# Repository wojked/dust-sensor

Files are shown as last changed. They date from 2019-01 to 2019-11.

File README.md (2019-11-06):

**This is a part of: https://dustsensor.net/**

__Links to the parts contain Banggood's affilate metadata.__

# Intro
I needed a PM2.5/PM10 sensor during this winter season. I wanted to monitor more than one room and did not want to buy multiple expensive devices.

This is an eclosure designed to fit 3 devices:
1. a PM2.5/PM10 dust sensor
2. a Wemos ESP8266-based board with an OLED display
3. a digital humidity and temperature sensor

# Parts
* Wemos NodeMCU with an OLED display
The brain of this project. Provides processing, connectivity and instant data feed on the display.
[Buy Wemos with a display](https://www.banggood.com/Wemos-Nodemcu-Wifi-For-Arduino-And-NodeMCU-ESP8266-0_96-Inch-OLED-Board-p-1154759.html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)

* Nova SDS011 
The main sensor used to measure PM2.5 and PM10
[Buy SDS011](https://www.banggood.com/Nova-PM-Sensor-SDS011-High-Precision-Laser-PM2_5-Air-Quality-Detection-Sensor-Module-p-1144246.html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)

* DHT22 (AM2302) 
Additional sensor to measure humidity and temperature
[Buy DHT22](https://www.banggood.com/AM2302-DHT22-Temperature-And-Humidity-Sensor-Module-For-Arduino-SCM-p-937403.html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)

* 4x longer M3x20 screws to hold the main case plates together 
[Buy M3x20](https://www.banggood.com/Suleve-M3CH9-50Pcs-M3-Carbon-Steel-Hex-Socket-Cap-Head-Screws-Bolts-4-20mm-Optional-Length-p-1217022.html?ID=514050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)
* 4x shorter M3x8 screws to mount the Wemos board
[Buy M3x8](https://www.banggood.com/Suleve-M3CH9-50Pcs-M3-Carbon-Steel-Hex-Socket-Cap-Head-Screws-Bolts-4-20mm-Optional-Length-p-1217022.html?ID=513285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)

# Assembly
1. Print the parts
2. Connect SDS011 to Wemos board
3. Connect DHT22 to Wemos board
4. Use 4x shorter screws to mount the Wemos board to the front plate
5. Use 4x longer screws to keep front and back plate together
6. Flash Wemos board with [ESPEasy](https://github.com/letscontrolit/ESPEasy)
7. Configure devices in ESPeasy

# Summary
When fully assembled, it should be compete with the retail products as:

* [Xiaomi PM2.5 detector](https://www.banggood.com/Original-Xiaomi-Mijia-PM2_5-Detector-Air-Quality-Tester-Monitor-OLED-Smart-Sensor-Air-Purifier-p-1330361.html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)

* [SNDWAY SW-825 Digital Air Quality Monitor](https://www.banggood.com/SNDWAY-SW-825-Digital-Air-Quality-Monitor-Laser-PM2_5-Detector-Gas-Temperature-Humidity-Monitor-p-1244753.html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)

# Please feel free to propose improvements
https://github.com/wojked/dust-sensor

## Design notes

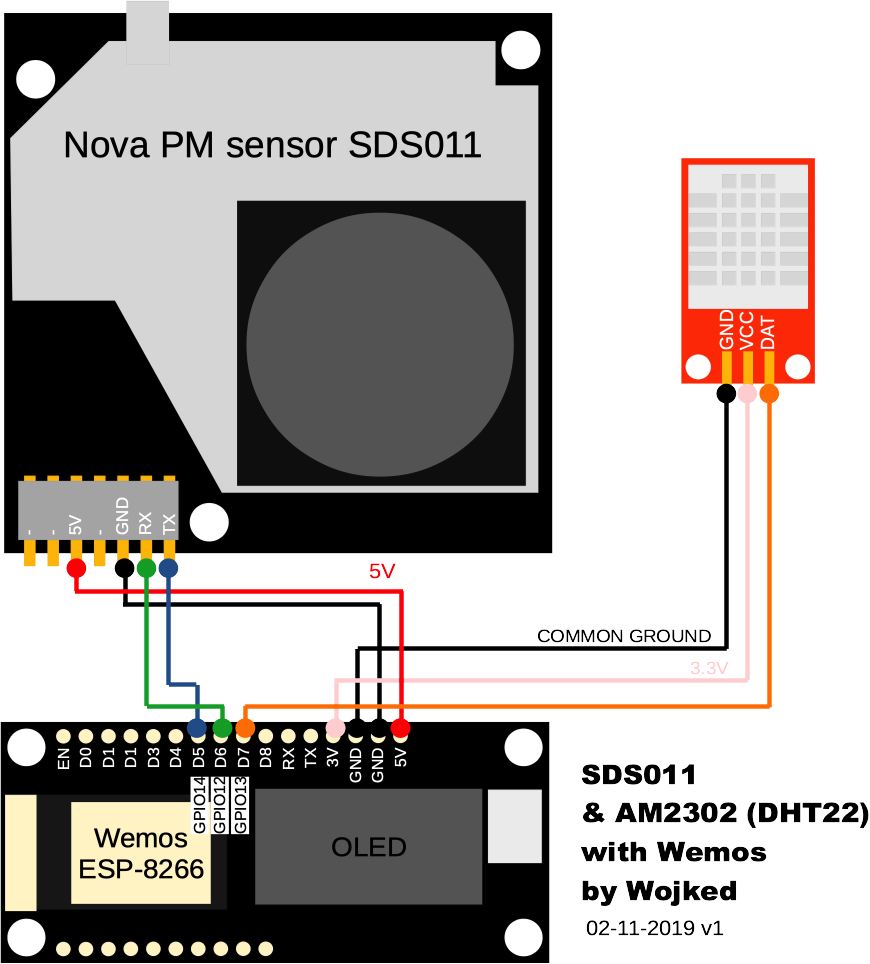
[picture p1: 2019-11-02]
diagram.png

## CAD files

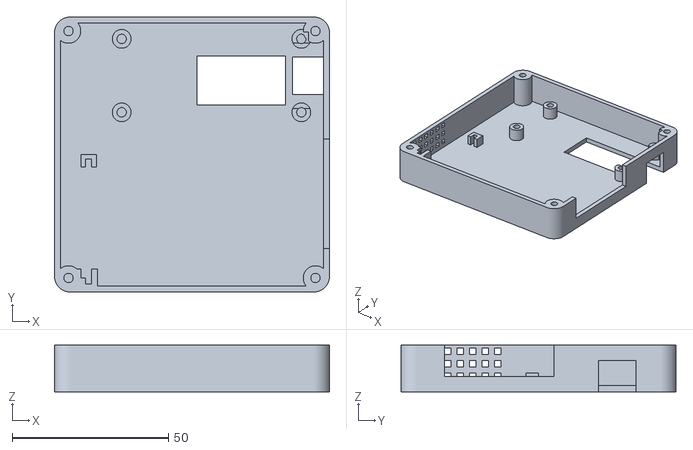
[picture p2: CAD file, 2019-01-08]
dust-sensor-front.stl
88.0 x 88.0 x 15.0

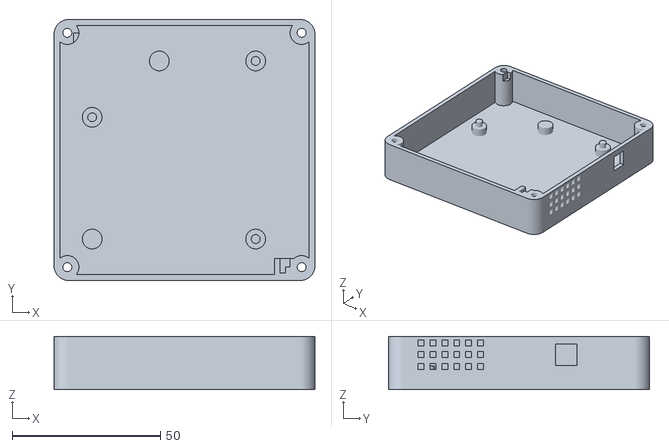
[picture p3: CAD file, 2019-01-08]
dust-sensor-back.stl
88.0 x 88.0 x 18.0

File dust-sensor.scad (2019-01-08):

EXTRA_MARGIN = 14; // initially 6
SENSOR_WIDTH = 70 + EXTRA_MARGIN;
SENSOR_HEIGHT = 70 + EXTRA_MARGIN;

BASE_THICKNESS = 2; // initially 1
CORNER_CURVE_DIAMETER = 10; // initially 3

WALL_THICKNESS = 2;
TOTAL_WALL_HEIGHT = 32; // initially 25
WALL_HEIGHT = 18;
FRONT_WALL_HEIGHT = TOTAL_WALL_HEIGHT - WALL_HEIGHT + BASE_THICKNESS - 1; // Fix with BASE_THICKNESS - 1 (initial thickness was 1)


/* [MOUNTING ELEMS] */
HOLE_DIAMETER = 3.0; // initially 2.7
HOLE_HOLDER = 6.65;
SCREW_WALL_THICKNESS = 2;
SCREW_HEAD_DIAMETER = 6.4; // M3 screw
SCREW_HEAD_THICKNESS = 3.07; // M3 screw
SCREW_OFFSET = 0.7;


//Cut-outs dimensions
CABLE_PORT_HEIGHT = 21;
AIR_INTAKE_DIAMETER = 7.15;
FAN_SIZE = 35;
FAN_HEIGHT = 10;

PCB_THICKNESS = 1.64;
TOTAL_PCB_THICKNESS = 4.10;
CHIP_THICKNESS = TOTAL_PCB_THICKNESS - PCB_THICKNESS + 1; //initially +0.5
SLOT_HEIGHT = CHIP_THICKNESS + 2.5; //initially + 2

// WEMOS
WEMOS_WIDTH = 61.5;
WEMOS_HEIGHT = 27.5;

WEMOS_TOTAL_THICKNESS = 4.8;
WEMOS_PCB_THICKNESS = PCB_THICKNESS;
WEMOS_SUPPORT_HEIGHT = WEMOS_TOTAL_THICKNESS - WEMOS_PCB_THICKNESS + 2;

WEMOS_OFFSET = 5;
WEMOS_SCREW_OFFSET = 0.5;   //initially 0.8

//DHT22
DHT_WIDTH = 21;
DHT_HEIGHT = 16;
DHT_WIDHT_WITH_HEADER = 26;
DHT_THICKNESS = 7.8;
DHT_HEADER_THICKNESS = 1.6;
DHT_BACK_OFFSET = 2;

DHT_RED_PCB_WIDTH = 40;
DHT_RED_PCB_HEIGHT = 23;
DHT_RED_PCB_THICKNESS = 1.8;
DHT_RED_PCB_OFFSET = 3;
DHT_OFFSET = 8;

OBJ_VISIBLE = false;

EXPLODE = 0;
ROTATE = 180;


$fn = 128;

//dust_sensor_back();  

translate([0, 0, WALL_HEIGHT + EXPLODE])
rotate([0,ROTATE,0])
dust_sensor_front();

module air_grill(){
    hole_width = 2;
    hole_separator = 2;
    translate_step = hole_width + hole_separator;
    length = 10;
    
    initial_translation = translate_step;
    translate([length/2, -initial_translation, 0])
    for (n = [0:1:5]){
        translate([0,n*translate_step, 0]) 
        cube([length,hole_width,hole_width], true);    
    };     
}

module air_grill_set(){
    translate([0,-5,7])
    air_grill();
    
    translate([0,-5,3])
    air_grill();
    
    translate([0,-5,-1])
    air_grill();        
    
    translate([0,-5,-5])
    air_grill();         
    
    translate([0,-5,-9])
    air_grill();  

    translate([0,-5,-13])
    air_grill();      
}

module dht22redpcb(){
    color("red")     
    cube([DHT_RED_PCB_THICKNESS,DHT_RED_PCB_WIDTH,DHT_RED_PCB_HEIGHT], true);     
}

module dht22whitepart(){
    union(){
        cube([DHT_THICKNESS,DHT_WIDTH,DHT_HEIGHT], true);    
        
        translate([-(DHT_THICKNESS-DHT_HEADER_THICKNESS)/2,(DHT_WIDTH-DHT_WIDHT_WITH_HEADER)/2,0])
        cube([DHT_HEADER_THICKNESS,DHT_WIDHT_WITH_HEADER,DHT_RED_PCB_HEIGHT], true);    
        
        translate([0,0,1.5])
        air_grill_set();
    }    
}

module dht22(){
    union(){
        color("red")
        dht22redpcb();
        
        color("white")
        translate([(DHT_RED_PCB_THICKNESS + DHT_THICKNESS)/2-0.001,(DHT_RED_PCB_WIDTH - DHT_WIDTH)/2 - 12,0])
        dht22whitepart();       
    }
}

module screw_head(height) {;
    cylinder(height,SCREW_HEAD_DIAMETER/2, SCREW_HEAD_DIAMETER/2, true);      
}

module screw_pole(height, additional_thickness){
    pole_diameter = HOLE_DIAMETER + 2*SCREW_WALL_THICKNESS + additional_thickness;
    cylinder(height,pole_diameter/2, pole_diameter/2, true);              
}

module screw_tunnel(height){
    color("white")    
    cylinder(height,HOLE_DIAMETER/2, HOLE_DIAMETER/2, true);                  
}

module screw_port(height){
    screw_diameter = HOLE_DIAMETER + 2*SCREW_WALL_THICKNESS;
    
    difference(){
        cylinder(height,screw_diameter/2, screw_diameter/2, true);              
        cylinder(height*2,HOLE_DIAMETER/2, HOLE_DIAMETER/2, true);              
    }
}

module screw_heads(){
    screw_depth = 3;
    translate_x = (SENSOR_WIDTH-SCREW_HEAD_DIAMETER)/2+SCREW_OFFSET;
    translate_y = (SENSOR_HEIGHT-SCREW_HEAD_DIAMETER)/2+SCREW_OFFSET;    

    union(){      
        color("red")
        translate([translate_x,translate_y,screw_depth/2])
        screw_head(screw_depth);     

        color("red")
        translate([-translate_x,translate_y,screw_depth/2])
        screw_head(screw_depth);             
        
        color("red")
        translate([-translate_x,-translate_y,screw_depth/2])
        screw_head(screw_depth);           
        
        color("red")
        translate([translate_x,-translate_y,screw_depth/2])
        screw_head(screw_depth);    
    }
}

module screw_poles(height, additional_thickness){
    screw_depth = 10;
    translate_x = (SENSOR_WIDTH-SCREW_HEAD_DIAMETER)/2+SCREW_OFFSET;
    translate_y = (SENSOR_HEIGHT-SCREW_HEAD_DIAMETER)/2+SCREW_OFFSET;    

    translate([0,0,height/2])
    union(){      
        color("red")
        translate([translate_x,translate_y,0])
        screw_pole(height, additional_thickness);     

        color("red")
        translate([-translate_x,translate_y,0])
        screw_pole(height, additional_thickness);     
        
        color("red")
        translate([-translate_x,-translate_y,0])
        screw_pole(height, additional_thickness);       
        
        color("red")
        translate([translate_x,-translate_y,0])
        screw_pole(height, additional_thickness);     
    }    
}

module dht22_holder(height){
    size = SCREW_HEAD_DIAMETER-1;
    
    translate([size/2,size/2,height/2])
    color("blue")
    cube([size*2,size,height], true);      
}

module screw_tunnels(height){
    screw_depth = 10;
    translate_x = (SENSOR_WIDTH-SCREW_HEAD_DIAMETER)/2+SCREW_OFFSET;
    translate_y = (SENSOR_HEIGHT-SCREW_HEAD_DIAMETER)/2+SCREW_OFFSET;    

    translate([0,0,height/2])
    union(){      
        translate([translate_x,translate_y,0])
        screw_tunnel(height*2);     

        translate([-translate_x,translate_y,0])
        screw_tunnel(height*2);               
        
        translate([-translate_x,-translate_y,0])
        screw_tunnel(height*2);            
        
        translate([translate_x,-translate_y,0])
        screw_tunnel(height*2);     
    }    
}

module dust_sensor_back(dust_sensor) { 
    wemos_wall_dist=3;
    wemos_fix_offset = 0.2;
    difference(){
        union(){
            translate([0, 0, BASE_THICKNESS/2])
            base();
            
            translate([0, 0, WALL_HEIGHT/2])
            base_with_walls(WALL_HEIGHT);        

            screw_poles(WALL_HEIGHT, 0.8);        
            
            translate([SENSOR_WIDTH/2 - 9, -SENSOR_HEIGHT/2, 0])
            dht22_holder(WALL_HEIGHT);      
      
    
        //    // WEMOS
        //    translate([-(SENSOR_WIDTH-WEMOS_WIDTH)/2+WEMOS_OFFSET,(SENSOR_HEIGHT-WEMOS_HEIGHT)/2-wemos_wall_dist,BASE_THICKNESS+WALL_HEIGHT-2])
        //    rotate([0,0,180])    
        //    scale([1,1,4])
        //    wemos_thick_plate();    
            translate([(SENSOR_WIDTH-HOLE_DIAMETER-EXTRA_MARGIN)/2-9.5, (SENSOR_HEIGHT-HOLE_DIAMETER-EXTRA_MARGIN)/2-3.48, BASE_THICKNESS])    
            screw_slot();
            
            // Extra stabilizer
            translate([-(SENSOR_WIDTH-HOLE_DIAMETER-EXTRA_MARGIN)/2+25, (SENSOR_HEIGHT-HOLE_DIAMETER-EXTRA_MARGIN)/2-3.48, BASE_THICKNESS])        
            stabiliser();  
            
            translate([-(SENSOR_WIDTH-HOLE_DIAMETER-EXTRA_MARGIN)/2+2.37, (SENSOR_HEIGHT-HOLE_DIAMETER-EXTRA_MARGIN)/2-22.47, BASE_THICKNESS])    
            screw_slot();    
            
            translate([(SENSOR_WIDTH-HOLE_DIAMETER-EXTRA_MARGIN)/2-9.5, -(SENSOR_HEIGHT-HOLE_DIAMETER-EXTRA_MARGIN)/2+3.48, BASE_THICKNESS])    
            screw_slot();       
            
            // Extra stabilizer
            translate([-(SENSOR_WIDTH-HOLE_DIAMETER-EXTRA_MARGIN)/2+2.37, -(SENSOR_HEIGHT-HOLE_DIAMETER-EXTRA_MARGIN)/2+3.48, BASE_THICKNESS])    
            stabiliser();            
        };  
        
        screw_heads();        
        screw_tunnels(WALL_HEIGHT);
              
//        // CABLES
//        color("red")
//        translate([-SENSOR_WIDTH/2, (SENSOR_HEIGHT-CABLE_PORT_HEIGHT-EXTRA_MARGIN)/2, BASE_THICKNESS+WALL_HEIGHT/2+2]) //Extra +2
//        cube([8,CABLE_PORT_HEIGHT,WALL_HEIGHT], true);         

        // WEMOS - cutout - fix
        translate([-(SENSOR_WIDTH-WEMOS_WIDTH)/2+WEMOS_OFFSET-wemos_fix_offset,(SENSOR_HEIGHT-WEMOS_HEIGHT)/2-wemos_wall_dist+wemos_fix_offset,BASE_THICKNESS+WALL_HEIGHT-2])
        rotate([0,0,180])    
        scale([1,1,4])   
        wemos_thick_plate();

        // AIR INTAKE      
        color("red")
        translate([SENSOR_WIDTH/2, (SENSOR_HEIGHT-AIR_INTAKE_DIAMETER-EXTRA_MARGIN)/2-15.5, BASE_THICKNESS+AIR_INTAKE_DIAMETER/2+6.2])
        cube([8,AIR_INTAKE_DIAMETER,AIR_INTAKE_DIAMETER], true);
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

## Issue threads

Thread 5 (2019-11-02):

source code missing

fcauwe, 2019-11-02:
I would love to try to build the same sensor, but i'm missing the source code.
Can you also publish it?

wojked, 2020-01-03:
This is a code of the case, firmware is another project:
https://github.com/letscontrolit/ESPEasy

wojked, 2020-01-03:
If you need more info please visit my website that describes the configuration process as there is no need to build anything from the firmware source code, just clicking through the web panel:
https://dustsensor.net/firmware/

Closed 2020-01-03.

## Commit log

2018-11-04 First commit of the case.
    [dust-sensor.scad, dust-sensor.stl]
2018-11-04 Added walls and increases by an extra margin.
    [dust-sensor.scad, dust-sensor.stl]
2018-11-09 Holders have a wider pin. Added FAN slot.
    [dust-sensor.scad]
2018-11-09 STL updated.
    [dust-sensor.stl]
2018-11-10 Adding the front face
    [dust-sensor.scad]
2018-11-10 Front face with OLED cut outs.
    [dust-sensor.scad]
2018-11-10 Added front face.
    [dust-sensor-front.stl]
2018-11-10 Front with Wemos mounts.
    [dust-sensor-front.stl, dust-sensor.scad]
2018-11-11 More offset in the supports. Adding the intiial DHT22 slot.
    [dust-sensor-front.stl, dust-sensor.scad]
2018-11-11 Added the screws to connect the both parts.
    [dust-sensor.scad]
2018-11-11 Added back STL.
    [dust-sensor-back.stl]
2018-11-11 Taller walls
    [dust-sensor-back.stl, dust-sensor.scad]
2018-11-11 Slots added.
    [dust-sensor-back-14.stl, dust-sensor-front-14.stl, dust-sensor.scad]
2018-11-12 Minor cutout for wemos PCB.
    [dust-sensor-back-14.stl, dust-sensor.scad]
2018-11-12 Hidden the wemos_plate. Longer screw_tunnels.
    [dust-sensor-front-14.stl, dust-sensor.scad]
2018-11-12 Thicker screws poles.
    [dust-sensor.scad]
2018-11-12 STLs added.
    [dust-sensor-back-14.stl, dust-sensor-back.stl, dust-sensor-front-14.stl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]
2018-11-12 Quick fix for the screw port.
    [dust-sensor-back-14.stl, dust-sensor.scad]
2018-11-12 Thicker version.
    [dust-sensor-front-14.stl, dust-sensor.scad]
2018-11-17 Fixed the base.
    [dust-sensor.scad]
2018-11-17 Wemos screw offset fix.
    [dust-sensor.scad]
2018-11-17 Air intake modification.
    [dust-sensor.scad]
2018-11-17 DHT22 added with the "red pcb".
    [dust-sensor-back-14.stl, dust-sensor-back.stl, dust-sensor-front-14.stl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]
2018-11-18 DHT22 should fit now.
    [dust-sensor.scad]
2018-11-18 Changed the dht22 support.
    [dust-sensor-back.stl, dust-sensor-front.stl, dust-sensor.scad]
2018-11-18 Thicker wemos plate (cutout for the screw).
    [dust-sensor.scad]
2018-11-18 STL fixed too.
    [dust-sensor-front.stl]
